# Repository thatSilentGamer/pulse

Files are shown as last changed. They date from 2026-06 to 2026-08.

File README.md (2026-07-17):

# Custom ESP32-S3 Spotify Controller Macro-Pad

A hardware macro-pad designed from scratch to provide physical control over Spotify and computer audio. This project features mechanical keyswitches, a rotary encoder for volume tracking, and an integrated display for media status.

---

## Project Overview

### What It Is
This is a compact hardware macro-pad designed as a **Spotify Controller**. It features two **Cherry MX2A Speed Silver switches** for skipping tracks or pausing music, an **EC11 rotary encoder** for volume scrolling, and a **TENSTAR ROBOT 1x9 Pin SPI Display** tilted at an angle to show track info.

### Why I Made It
I engineered this controller to bridge digital media apps with hardware. The goal was to build a dedicated desktop tool that lets me control music instantly without switching windows.

### How It Works
* **Media Switches:** The Cherry MX2A Speed Silvers are soldered directly to a custom PCB, passing through a top case layer for stability.
* **Volume Encoder:** Provides a rotating dial interface to control system volume or track scrolling, and it has an integrated click-switch.
* **Display Output:** The sequential 1x9 pin header channels hardware SPI communication straight from the ESP32-S3 Mini, enabling graphics for media feedback.
* **Power & Control:** Fully powered and controlled via a USB-C connection driven by the ESP32-S3 Mini processor.

---

## Project Gallery











pulse_zine_page

---

## Mechanical & CAD Design

**[Click here to view the Onshape 3D CAD Assembly & Source Files](https://cad.onshape.com/documents/9e875fa0eb3d29beb0a7e423/w/634ce2adc409bcbb121e172c/e/cf97eb71c9d871e1e5143c14)**

The case is a two-part shell (top piece and bottom base) that is secured together using **M2/M3 mechanical screws through internal mounting standoffs** that align with the PCB's mounting holes (H1–H4). This ensures a rigid, durable enclosure that holds the electronics firmly in place without relying on friction, tape, or glue.

* **Material Clearances:** The switch holes are slightly larger than they need to be so that they don't get stuck if the 3D print shrinks or over-extrudes a bit.
* **Flush Screen Housing:** The angled part for the screen meets the flat top completely flush so there isn't a weird lip sticking out.
* **Vertical Component Stack:** The case is deep enough so the pins on the bottom of the PCB don't hit the bottom of the shell.

---

## Build Guide & Instructions

### 1. Bill of Materials (BOM)
| Item Name | Size / Specs | Quantity | Cost (Each) | Total Cost | Purchase Link |
| :--- | :--- | :---: | :---: | :---: | :--- |
| ESP32 | 38pin type c | 1 | $8.80 | $8.80 | [AliExpress Link](https://www.aliexpress.us/item/3256804511368849.html) |
| Cherry MX2A Speed Silver 45g Linear Switch | PCB RGB LED | 2 | $0.40 | $0.80 | [Mechanical Keyboards Link](https://mechanicalkeyboards.com/products/cherry-mx2a-speed-silver-45g-linear?variant=48015859876140) |
| EC11 w/ Push Button (rotary encoder) | 20mm Plum handle | 1 | $0.96 | $0.96 | [AliExpress Link](https://www.aliexpress.us/item/3256806507128635.html) |
| Encoder Knob | O 20x13mm | 1 | $0.99 | $0.99 | [AliExpress Link](https://www.aliexpress.us/item/3256808286803013.html) |
| TFT Display | 3.5 inch | 1 | $0.99 | $0.99 | [AliExpress Link](https://www.aliexpress.us/item/3256805988905985.html) |
| WS2812 LED Light strip | 1m | 1 | $0.99 | $0.99 | [AliExpress Link](https://www.aliexpress.us/item/3256806235758108.html) |
| Shine-through keycaps | Black-97 | 1 | $8.35 | $8.35 | [AliExpress Link](https://www.aliexpress.us/item/3256808975886837.html) |
| USB-C Cable | 100W Black | 1 | $5.28 | $5.28 | [AliExpress Link](https://www.aliexpress.us/item/2255800615813072.html) |
| 22AWG Electric Wire | 25m | 1 | $0.99 | $0.99 | [AliExpress Link](https://www.aliexpress.us/item/3256807019779669.html) |
| Resistor Set | 300pcs in box | 1 | $3.37 | $3.37 | [AliExpress Link](https://www.aliexpress.us/item/3256807120498276.html) |
| Capacitor Set | n/a | 1 | $2.05 | $2.05 | [AliExpress Link](https://www.aliexpress.com/item/3256806914843833.html) |
| Electrolytic Capacitor | 10V1000UF 20PCS | 1 | $0.99 | $0.99 | [AliExpress Link](https://www.aliexpress.us/item/3256810280290722.html) |
| Brass Heatset inserts | M2, M2.5, M3 (500PCS) | 1 | $1.59 | $1.59 | [AliExpress Link](https://www.aliexpress.us/item/3256805603102147.html) |
| M2 Screws | 482pcs M2 | 1 | $0.99 | $0.99 | [AliExpress Link](https://www.aliexpress.us/item/3256806973435795.html) |
| M3 Screws | 392pcs M3 | 1 | $0.99 | $0.99 | [AliExpress Link](https://www.aliexpress.us/item/3256806973435795.html) |
| 3D Printing | n/a | 1 | $10.00 | $10.00 | n/a |
| SK6812 MINI-E RGB lights | 100PCS | 1 | $0.99 | $0.99 | [AliExpress Link](https://www.aliexpress.us/item/3256805007401420.html) |
| | | | **Total Cost:** | **$48.72** | |

### 2. PCB & Wiring Layout
* The project utilizes a custom printed circuit board designed in KiCad (source files located in `/Electronics`). 
* **Switches:** Solder the Cherry MX2A Speed Silver switches into the footprint designated on the top side of the board.
* **Encoder:** Mount and solder the EC11 rotary encoder into position `SW1`.
* **Display:** Connect the 1x9 Pin SPI Display header directly to `J1`, which routes hardware SPI pins from the ESP32-S3 WROOM module.
* **Mounting:** Use M2/M3 mechanical screws through standoffs `H1`–`H4` to secure the soldered PCB firmly inside the 3D-printed bottom shell.

### 3. Firmware & Flashing Instructions
1. Download and install the Arduino IDE along with the ESP32 board definitions and required libraries (`TFT_eSPI`, `BleKeyboard`, `ESP32Encoder`, and `FastLED`).
2. Open `/Firmware/pulse.ino` in your IDE.
3. Connect the ESP32-S3 to your computer via USB-C.
4. Select **ESP32S3 Dev Module** as your target board and select the correct COM port.
5. Click **Upload** to compile and flash the firmware onto the microcontroller.

### 4. Usage Guide
Once flashed and powered via USB-C, Pulse will boot up and display *"Pulse is online."* on the screen while lighting up the green underglow.
* **Pairing:** Open your computer or phone's Bluetooth settings and pair with the device named **"Pulse Controller"**.
* **Volume Control:** Turn the rotary encoder knob clockwise to increase system volume, and counter-clockwise to decrease volume.
* **Play/Pause:** Press down on the rotary encoder knob (integrated click switch) to toggle media play/pause.
* **Track Navigation:** Press the left Cherry MX switch (`BTN_SKIP_BCK`) to jump to the previous track, or the right switch (`BTN_SKIP_FWD`) to skip to the next track on Spotify!

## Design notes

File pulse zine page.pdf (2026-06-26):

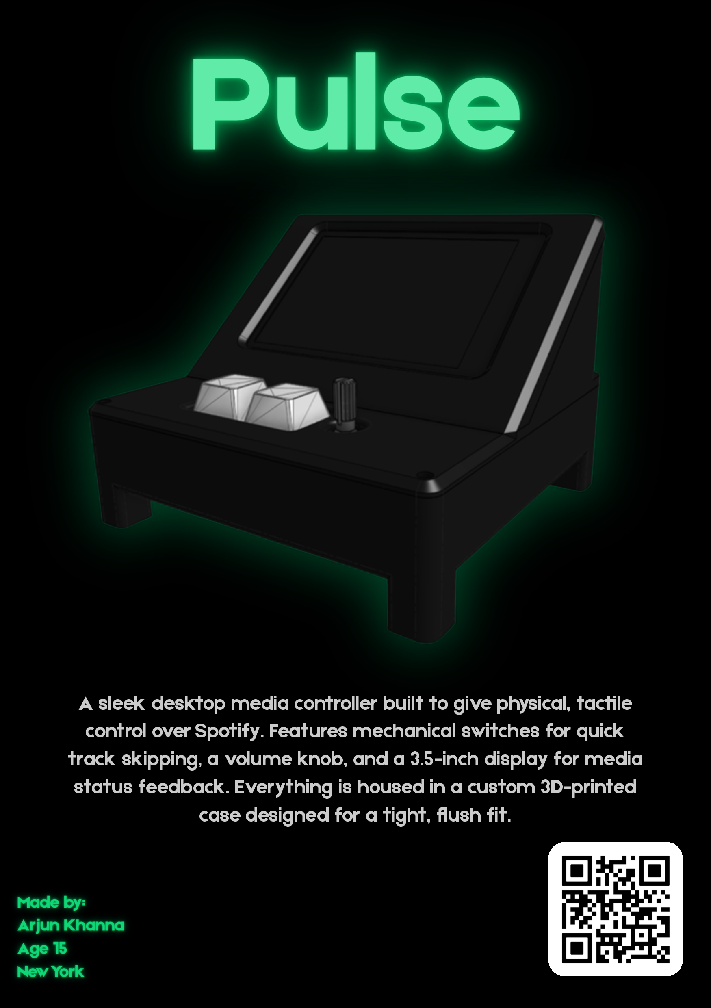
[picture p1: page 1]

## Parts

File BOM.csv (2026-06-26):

Item Name | Size | Quantity | Cost (Each) | Total Cost | Link
ESP32 | 38pin type c | 1 | 8.80 | 8.80 | https://www.aliexpress.us/item/3256804511368849.html?gatewayAdapt=glo2usa4itemAdapt
Cherry MX2A Speed Silver 45g Linear Switch | PCB RGB LED | 2 | 0.40 | 0.80 | https://mechanicalkeyboards.com/products/cherry-mx2a-speed-silver-45g-linear?variant=48015859876140
EC11 w/ Push Button (rotary encoder) | 20mm Plum handle | 1 | 0.96 | 0.96 | https://www.aliexpress.us/item/3256806507128635.html?curPageLogUid=TNzKFpQ5529N
Encoder Knob | O 20x13mm | 1 | 0.99 | 0.99 | https://www.aliexpress.us/item/3256808286803013.html?scm_id=1007.40050.354490.0&scm-url=1007.40050.354490.0
TFT Display | 3.5 inch | 1 | 0.99 | 0.99 | https://www.aliexpress.us/item/3256805988905985.html?gatewayAdapt=glo2usa
WS2812 LED Light strip | 1m | 1 | 0.99 | 0.99 | https://www.aliexpress.us/item/3256806235758108.html?curPageLogUid=LLzwZOcf2y7q
Shine-through keycaps | Black-97 | 1 | 8.35 | 8.35 | https://www.aliexpress.us/item/3256808975886837.html?curPageLogUid=l83MaH5p1L3j
USB-C Cable | 100W Black | 1 | 5.28 | 5.28 | https://www.aliexpress.us/item/2255800615813072.html?curPageLogUid=WaE4Avt80yv6
22AWG Electric Wire | 25m | 1 | 0.99 | 0.99 | https://www.aliexpress.us/item/3256807019779669.html?gatewayAdapt=glo2usa
Resistor Set | 300pcs in box | 1 | 3.37 | 3.37 | https://www.aliexpress.us/item/3256807120498276.html
Capacitor Set | n/a | 1 | 2.05 | 2.05 | https://www.aliexpress.com/item/3256806914843833.html
Electrolytic Capacitor | 10V1000UF 20PCS | 1 | 0.99 | 0.99 | https://www.aliexpress.us/item/3256810280290722.html?curPageLogUid=DG3RoeVSzZrx
Brass Heatset inserts | M2, M2.5, M3 (500PCS) | 1 | 1.59 | 1.59 | https://www.aliexpress.us/item/3256805603102147.html?scm_id=1007.14452.396806.0&scm-url=1007.14452.396806.0
M2 Screws | 482pcs M2 | 1 | 0.99 | 0.99 | https://www.aliexpress.us/item/3256806973435795.html?curPageLogUid=qroPY5ceMDZf
M3 Screws | 392pcs M3 | 1 | 0.99 | 0.99 | https://www.aliexpress.us/item/3256806973435795.html?curPageLogUid=qroPY5ceMDZf
3D Printing | n/a | 1 | 10.00 | 10.00 | n/a
SK6812 MINI-E RGB lights | 100PCS | 1 | 0.99 | 0.99 | https://www.aliexpress.us/item/3256805007401420.html?curPageLogUid=udDaWzcn05y4
 |  |  |  | Total Cost: | $48.72

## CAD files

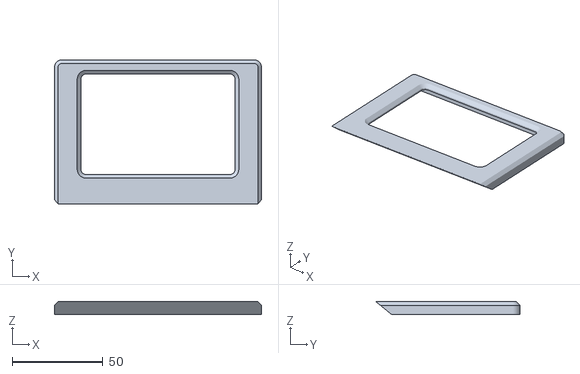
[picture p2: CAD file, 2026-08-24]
printing_files/Cover.stl
114.3 x 79.6 x 7.00

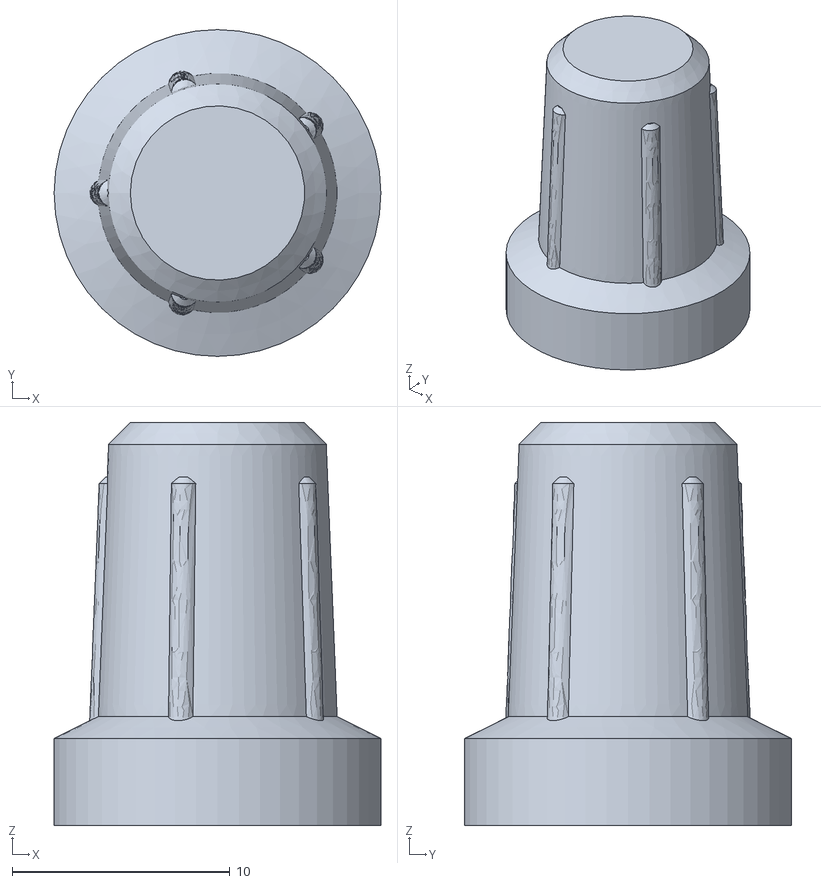
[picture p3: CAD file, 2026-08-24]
printing_files/Encoder_Knob.stl
15.0 x 15.0 x 18.5

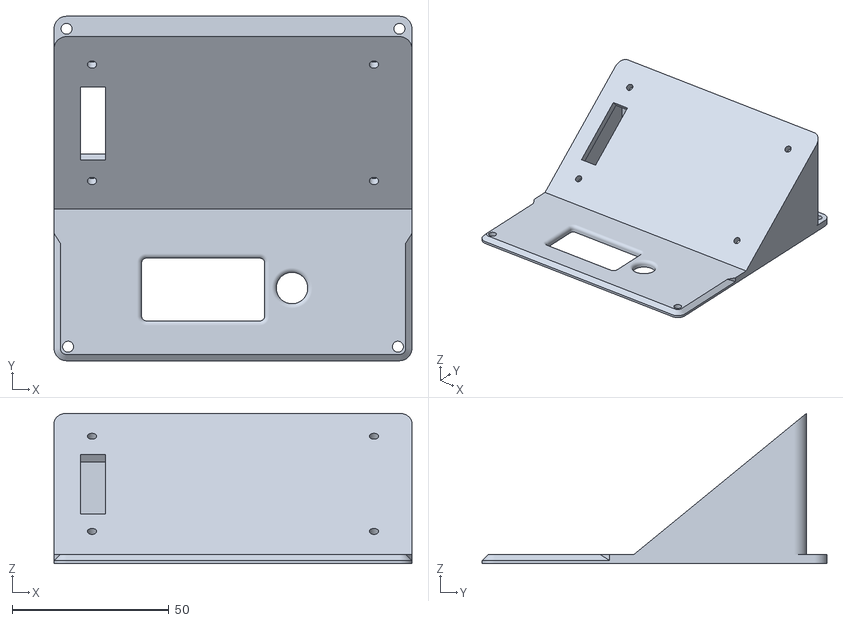
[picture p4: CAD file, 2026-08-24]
printing_files/Top.stl
114.3 x 110.0 x 48.0

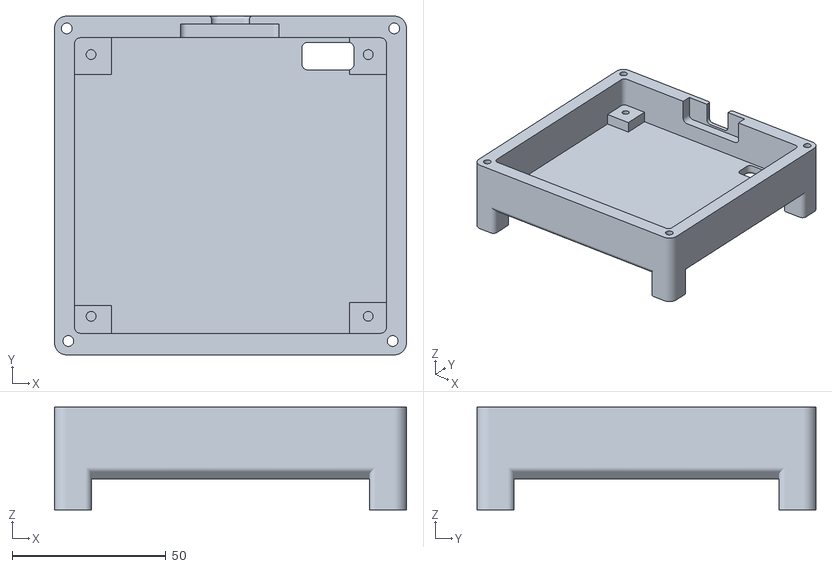
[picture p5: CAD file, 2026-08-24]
printing_files/Base.stl
114.3 x 110.0 x 33.4

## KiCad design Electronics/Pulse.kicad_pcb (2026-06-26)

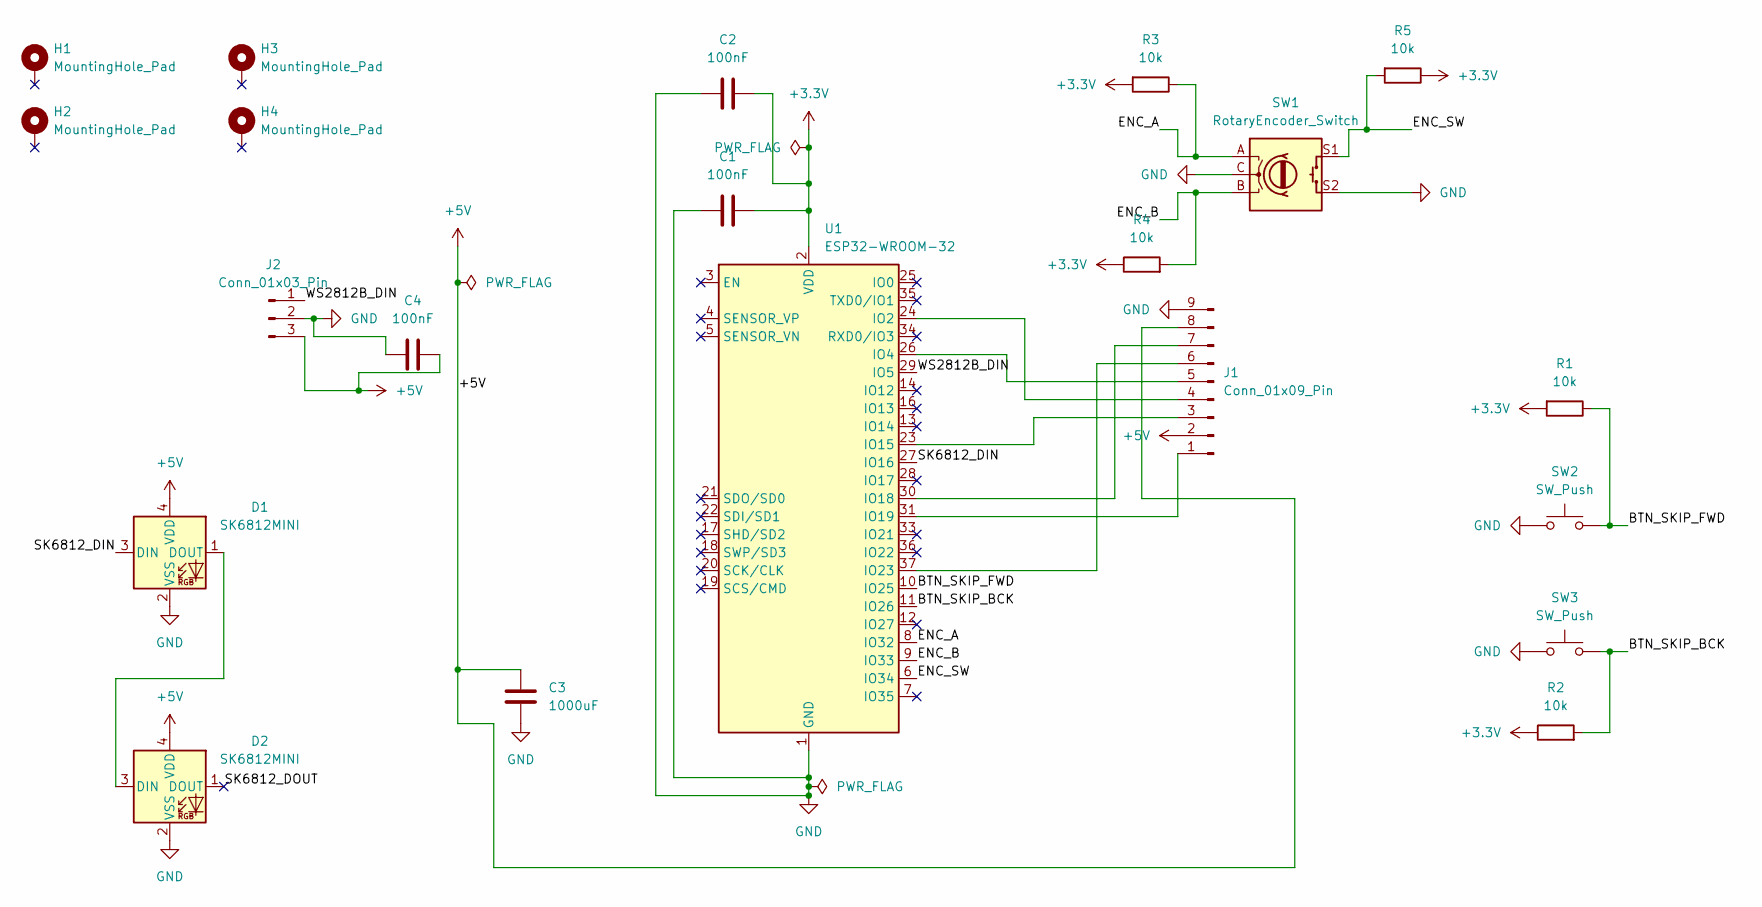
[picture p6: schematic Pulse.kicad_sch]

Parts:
C1, C2, C4: 100nF; C_Disc_D5.0mm_W2.5mm_P5.00mm
C3: 1000uF; C_Radial_D8.0mm_H11.5mm_P3.50mm
D1, D2: SK6812MINI; MX_SK6812MINI-E_REV
H1, H2, H3, H4: MountingHole_Pad; MountingHole_2.2mm_M2_Pad_Via
J1: Conn_01x09_Pin; PinHeader_1x09_P2.54mm_Vertical
J2: Conn_01x03_Pin; PinHeader_1x03_P2.54mm_Vertical
R1, R2, R3, R4, R5: 10k; R_Axial_DIN0207_L6.3mm_D2.5mm_P10.16mm_Horizontal
SW1: RotaryEncoder_Switch; RotaryEncoder_Alps_EC11E-Switch_Vertical_H20mm_CircularMoun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
SW2, SW3: SW_Push; SW_Cherry_MX1A_1.00u_PCB
U1: ESP32-WROOM-32; ESP32-DevKitC

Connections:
+3.3V: C1.2, C2.2, R1.2, R2.1, R3.2, R4.1, R5.1, U1.2 (VDD)
+5V: C3.2, C4.2, D1.4 (VDD), D2.4 (VDD), J1.2, J1.8, J2.3
/BTN_SKIP_BCK: R2.2, SW3.2, U1.11 (IO26)
/BTN_SKIP_FWD: R1.1, SW2.2, U1.10 (IO25)
/ENC_A: R3.1, SW1.A, U1.8 (IO32)
/ENC_B: R4.2, SW1.B, U1.9 (IO33)
/ENC_SW: R5.2, SW1.S1, U1.6 (IO34)
/SK6812_DIN: D1.3 (DIN), U1.27 (IO16)
/SK6812_DOUT: D2.1 (DOUT)
/WS2812B_DIN: J2.1, U1.29 (IO5)
GND: C1.1, C2.1, C3.1, C4.1, D1.2 (VSS), D2.2 (VSS), J1.9, J2.2, SW1.C, SW1.S2, SW2.1, SW3.1, U1.1 (GND)
unnamed: D1.1 (DOUT), D2.3 (DIN)
unnamed: J1.1, U1.31 (IO19)
unnamed: J1.3, U1.23 (IO15)
unnamed: J1.4, U1.24 (IO2)
unnamed: J1.5, U1.26 (IO4)
unnamed: J1.6, U1.37 (IO23)
unnamed: J1.7, U1.30 (IO18)

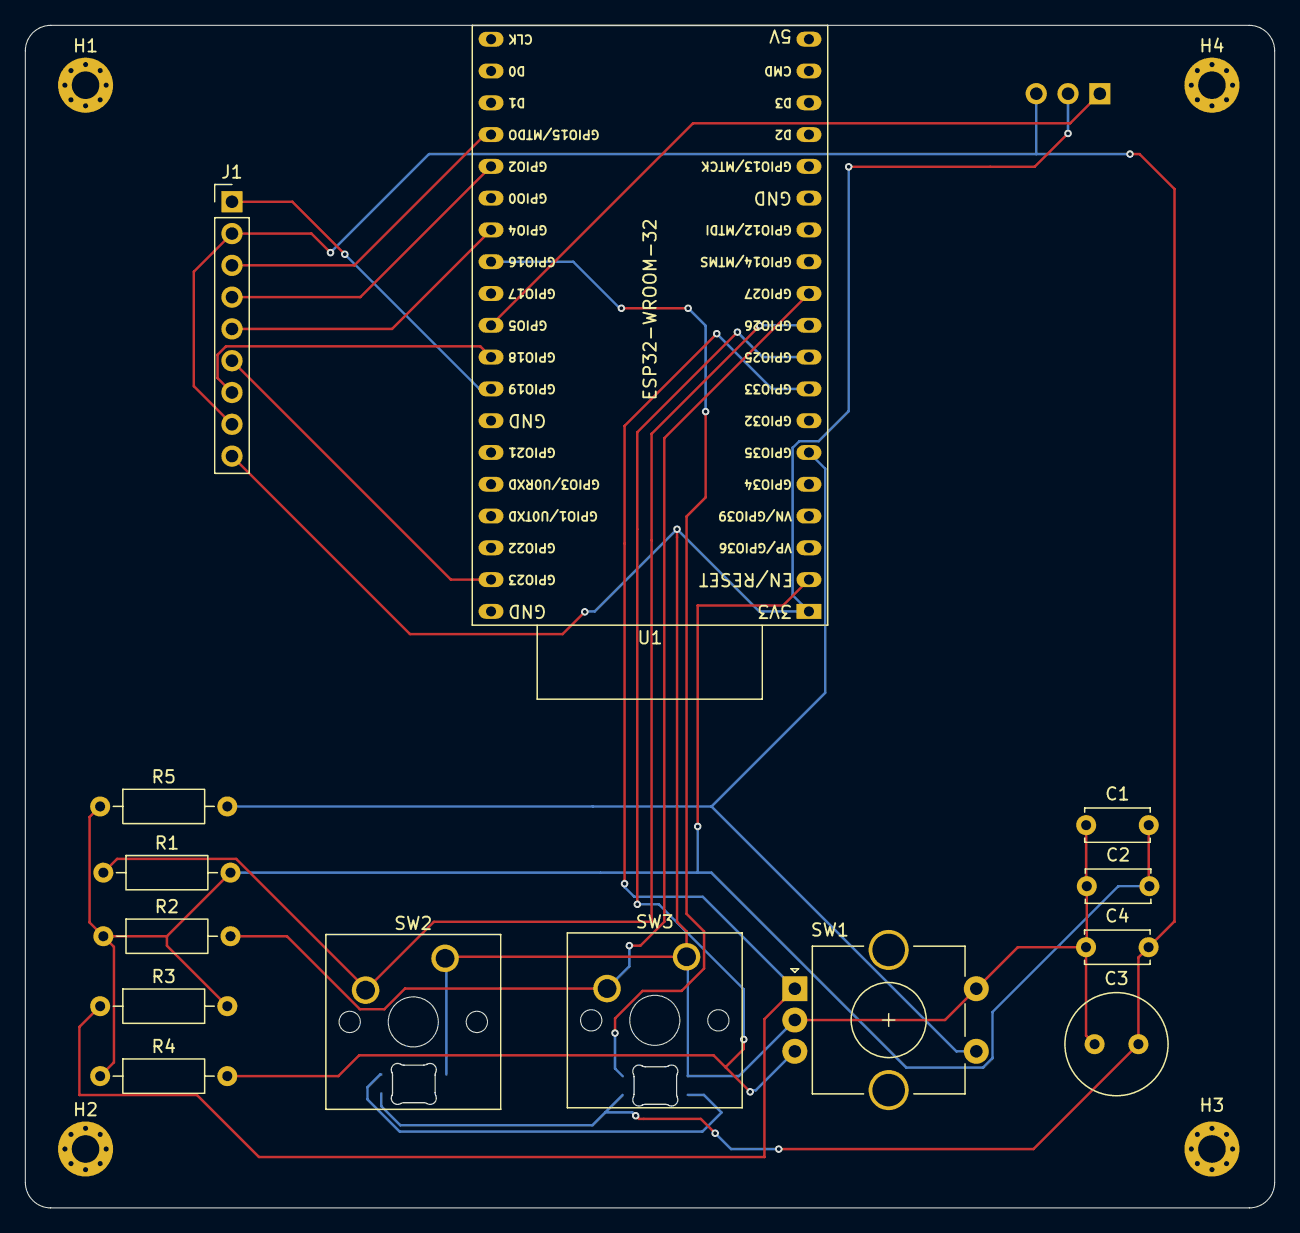
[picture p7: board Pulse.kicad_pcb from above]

Board: 2 copper layers, 99.8 x 94.5 mm, 21 parts (1 on the bottom side), 17 nets.

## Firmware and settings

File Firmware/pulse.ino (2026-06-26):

#include <TFT_eSPI.h>
#include <BleKeyboard.h>
#include <ESP32Encoder.h>
#include <FastLED.h>

// --- Pin Definitions ---
#define SW_PREV 26
#define SW_NEXT 25
#define ENC_A 32
#define ENC_B 33
#define ENC_BTN 34
#define WS2812_PIN 5
#define SK6812_PIN 16
#define NUM_LEDS 4

TFT_eSPI tft = TFT_eSPI();
BleKeyboard bleKeyboard("Pulse Controller", "Arjun", 100);
ESP32Encoder encoder;
CRGB leds[NUM_LEDS];

int lastEncoderCount = 0;

void setup() {
  Serial.begin(115200);

  // Hardware pull-ups are present on the PCB, so standard INPUT is perfect
  pinMode(SW_PREV, INPUT);
  pinMode(SW_NEXT, INPUT);
  pinMode(ENC_BTN, INPUT);

  // Initialize LEDs (Using the SK6812 data line for the switch underglow)
  FastLED.addLeds<WS2812, SK6812_PIN, GRB>(leds, NUM_LEDS);
  FastLED.setBrightness(60);
  fill_solid(leds, NUM_LEDS, CRGB::SpringGreen);
  FastLED.show();

  // Initialize Screen
  tft.init();
  tft.setRotation(1);
  tft.fillScreen(TFT_BLACK);
  tft.setTextColor(TFT_GREEN, TFT_BLACK);
  tft.drawString("Pulse is online.", 20, 20, 4);

  // Initialize Encoder
  encoder.attachHalfQuad(ENC_A, ENC_B);
  encoder.setCount(0);

  // Start Bluetooth HID
  bleKeyboard.begin();
}

void loop() {
  if (bleKeyboard.isConnected()) {
    
    // Check Previous Track Button
    if (digitalRead(SW_PREV) == LOW) {
      bleKeyboard.write(KEY_MEDIA_PREVIOUS_TRACK);
      delay(250); 
    }
    
    // Check Next Track Button
    if (digitalRead(SW_NEXT) == LOW) {
      bleKeyboard.write(KEY_MEDIA_NEXT_TRACK);
      delay(250);
    }
    
    // Check Play/Pause Encoder Button
    if (digitalRead(ENC_BTN) == LOW) {
      bleKeyboard.write(KEY_MEDIA_PLAY_PAUSE);
      delay(300);
    }

    // Check Volume Knob
    int currentCount = encoder.getCount();
    if (currentCount > lastEncoderCount) {
      bleKeyboard.write(KEY_MEDIA_VOLUME_UP);
      lastEncoderCount = currentCount;
    } else if (currentCount < lastEncoderCount) {
      bleKeyboard.write(KEY_MEDIA_VOLUME_DOWN);
      lastEncoderCount = currentCount;
    }
  }
  delay(10);
}

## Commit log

2026-06-26 Update README with project overview and design details
    Added detailed project description and specifications for the Custom ESP32-S3 Spotify Controller Macro-Pad.
2026-06-26 Update BOM.csv with total cost and item links
    Added total cost summary and updated item links.
    [BOM.csv]
2026-06-26 Update BOM.csv format and link syntax
    [BOM.csv]
2026-06-26 Fix formatting and links in BOM.csv
    Updated BOM.csv to correct formatting and links.
    [BOM.csv]
2026-06-26 Update BOM.csv with corrected links and formatting
    [BOM.csv]
2026-06-26 Revise BOM with new links and updated costs
    Updated product links and prices in BOM.csv.
    [BOM.csv]
2026-06-26 Update BOM.csv with new items and costs
2026-06-26 Update BOM.csv with new item entries
    [BOM.csv]
2026-07-09 Rename Screenshot 2026-07-09 151816.png to schematic_image
2026-07-09 Update PCB Schematic image in README
2026-07-09 Enhance Mechanical & CAD Design details in README
    Updated the Mechanical & CAD Design section with detailed assembly information and material clearances.
2026-07-17 Revise BOM section with detailed component list
    Updated the Bill of Materials (BOM) section with detailed item information, including names, sizes, quantities, costs, and links for each component required to build Pulse.
2026-07-17 Revise BOM formatting and links in README.md
    Updated the Bill of Materials (BOM) section with improved formatting and links.
2026-07-17 Fix duplicate Bill of Materials section in README
    Removed duplicate section header for Bill of Materials.
